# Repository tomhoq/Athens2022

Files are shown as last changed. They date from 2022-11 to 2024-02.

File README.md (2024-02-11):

# Athens2022-Madrid

Code for ESP32 client and server and Processing interface that display data.

With this project we came up with a solution for a long known problem present on our university: lack of studying spaces.

By using sensors on an Arduino board, connected wirelessly to a server, anyone is able to access, online, the occupancy of each studying room to 
make better decisions and to avoid having to walk the entire campus, up and down.

More on the functioning of the project can be found on the report.

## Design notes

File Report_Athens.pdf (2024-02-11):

### The doorman of the Future

A new approach to managing studying rooms

### UPM115 - Physical Computing based on Open Software and Hardware Platforms [EN]

Autores:

Ant´onio Vidais (IST - Lisboa) Tomaz Silva (IST - Lisboa) antonio.vidais@tecnico.ulisboa.pt tomaz.goncalves-silva@tecnico.ulisboa.pt

### Athens – Winter of 2022

IST | ULisboa

## 1 Introduction

The need for this system comes from the fact that every day, students trying to study on their college have to scour their entire college for a room where they can study. The Future Doorman solves this by sharing data from open rooms to everyone who needs it.
It is composed of 2 systems, a client that is attached to the door of each room and a server connected to a computer that can share the information either online or on a screen.

## 2 Choice of Hardware

### 2.1 Client

After some tries, we decided that the best platform available was the ESP32, because of the integrated Wifi module, without compromising on the number of GPIO pins and memory. However, choosing an ESP-WROOM-32 meant that 5v power wouldn’t be available. That meant that we couldn’t use ultrasound sensors. While searching for a 3.3v compatible distance sensor. We settled on LIDAR sensor because it provided the precision that the application requires and works on both 3.3v and 5v power.

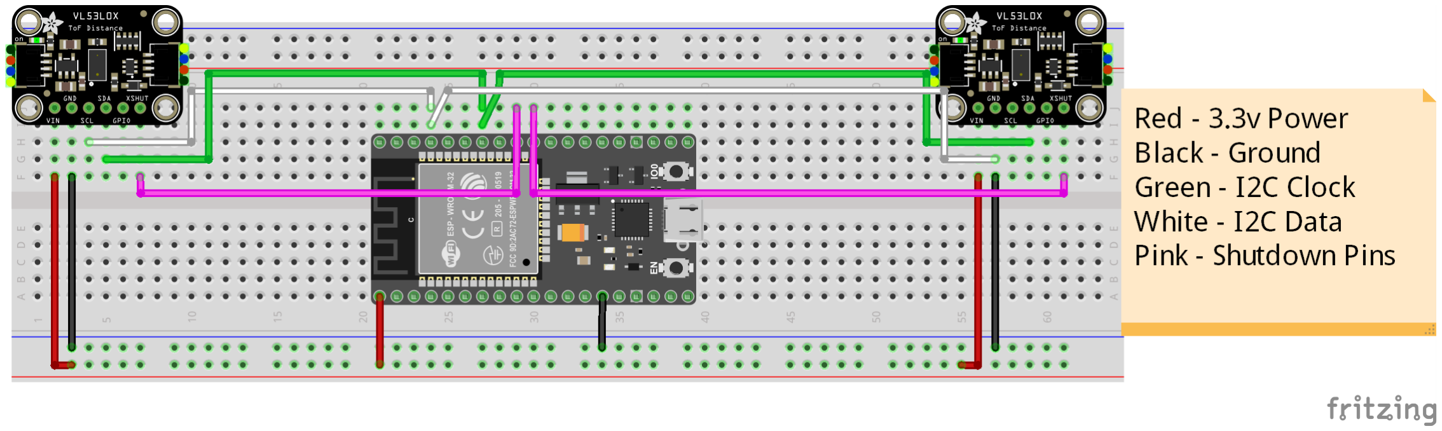
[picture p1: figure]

Figura 1: Client Schematic

### 2.2 Server

For the server we also wanted to use an ESP-WROOM-32 because of the compact size and, once again, the superior wifi module. The server doesn’t need any additional modules as it´s only function is to connect the server computer to the clients.

## 3 Hardware Limitations

As we tested the hardware, we realized that there was a limitation in the refresh rate of the LIDAR Sensors, as they would sometimes miss count if people are fast enough. This situation only happened rarely so it isn’t too much of a problem.
One Limitation that we couldn’t solve is that LIDAR sensors are dependent on colors, so we predict some unexpected behaviour if the background isn’t mono color.
We also noticed that the server and client would often have different refresh rates and getting them to match would be hard, so we had to separate the sensor reading from the data
Unidade Curricular | 1 | Curso

sending. We settled on using an HTTP server between the 2 modules, where the server requests data from the client and the client answers by sending both room and occupation data. This way both modules are independent and can work at different refresh rates.

## 4 Displaying data

To get the data from clients, the server sends multiple HTTP requests and then analyses the responses to get the data for each room. Responses give the server information on both room and occupation.
The data is displayed in a window as follows.
On the left side, the classrooms’ name surrounded by a color representing it’s percentage of occupation.
- Green: 0 to 30 percent of room is free;
- Yellow: 30 to 75 percent of the room is occupied;
- Red: More than 75 percent of the room is occupied;

(Note that it is possible to have more than 100 percent occupation and in this case it will also display red);

On the right of the classrooms’ name you can see how many people are inside the room and it’s maximum capacity.
On the right side of the window, 2 buttons that let the user sort the rooms in 2 ways that make it more convenient. One is alphabetically accordingly to the room’s name, and the other sorts based on the percentage of occupation of each room (from low to high).
In the case, where there are too many rooms and they don’t all fit in the windows’ resolution, a sliding animation begins, showing all the hidden rooms. Once it reaches the end, resets to the first room.
Unidade Curricular | 2 | Curso

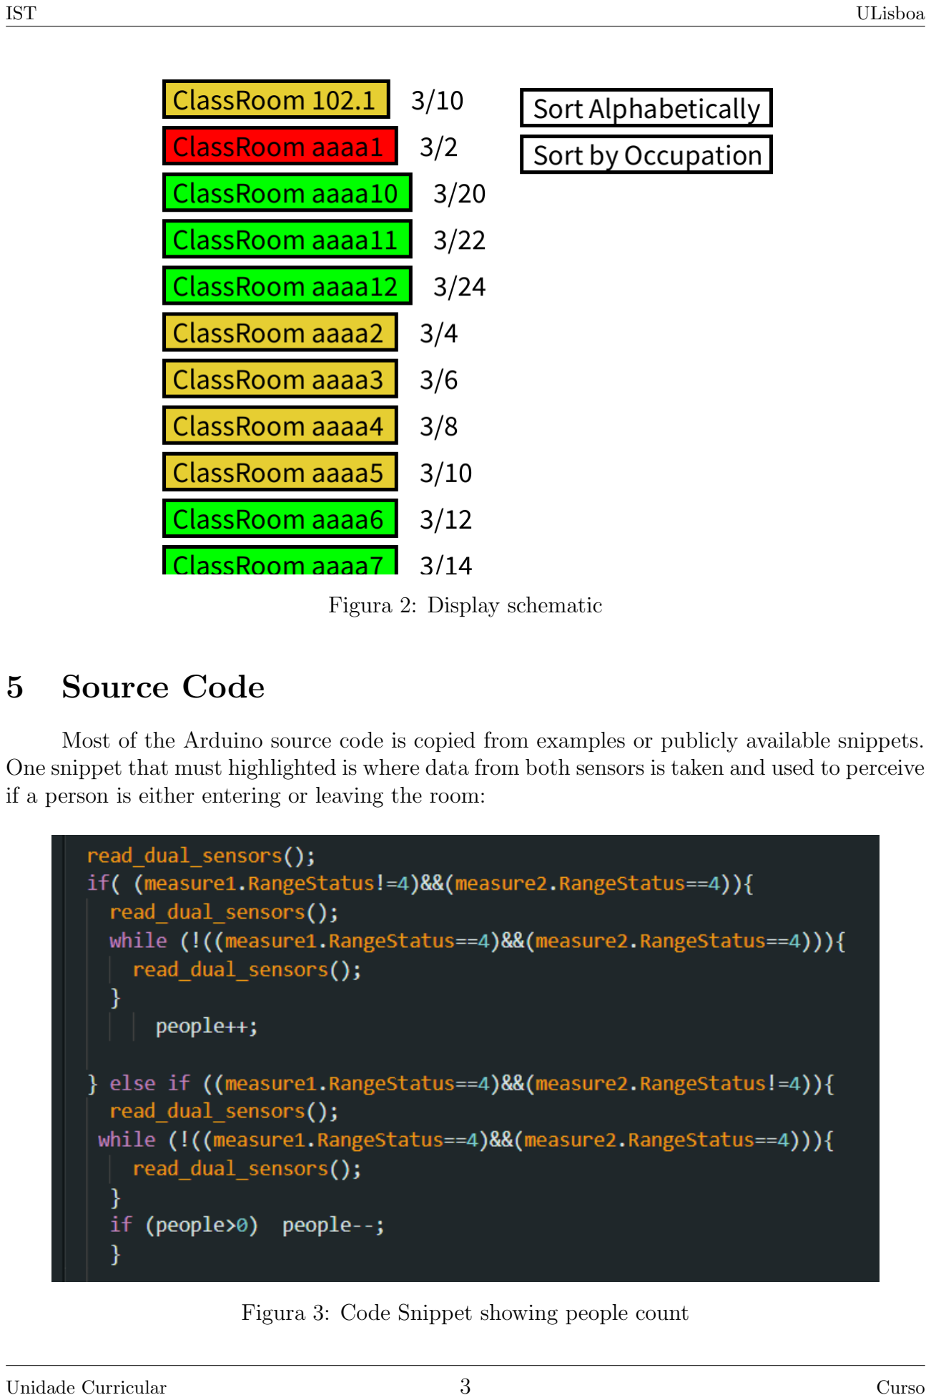
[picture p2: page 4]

Figura 2: Display schematic

## 5 Source Code

Most of the Arduino source code is copied from examples or publicly available snippets. One snippet that must highlighted is where data from both sensors is taken and used to perceive if a person is either entering or leaving the room:

Figura 3: Code Snippet showing people count

Unidade Curricular | 3 | Curso

The full source code can be found on GitHub (https://github.com/tomhoq/Athens2022.git)

## 6 Self-evaluation

### 6.1 What went wrong

There were some things that we intended to do extra but, unfortunately, due to issues with both breadboards and Arduino’s lost a lot of valuable time.

### 6.2 What went well

We were able to divide the work very efficiently with Ant´onio being responsible for designing and assembling the hardware (both client and server and the interaction between them) and Tomaz making sure the data gets treated, and then displaying it in an efficient and visually attractive User Interface.
By making the correct hardware choices, we were able to have a system that runs fully on 3.3v power, which reduces power consumption substantially.

### 6.3 The next steps

One important aspect this system lacks is the ability to calibrate the sensors. By having an initial measure of the background the system wouldn’t be as dependent on the LIDAR sensors accurate measuring.
This system has potential to grow if we wanted to. We can scale to it almost indefinitely because there isn’t a necessity for high refresh rates. One server can have many clients without problems which makes integration on big universities simpler than other systems.
The object of this system is to help students, so our initial idea was to have occupation data shown on an app (or a website), where students could quick and easily find a room to study in.

## 7 Conclusion

During this project we were challenged many times, with problems that an engineer designing a similar system only gets if he test real hardware. This is an important lesson in a world where everything is virtual. Our initial virtual designs appeared to work well but, as we found out, that wasn’t the case when it came to the real deal.

Unidade Curricular | 4 | Curso

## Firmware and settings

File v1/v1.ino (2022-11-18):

#include "Adafruit_VL53L0X.h"
#include "WiFi.h"
#include "ESPAsyncWebServer.h"

#include <Wire.h>

// address we will assign if dual sensor is present
#define LOX1_ADDRESS 0x30
#define LOX2_ADDRESS 0x31

// set the pins to shutdown
#define SHT_LOX1 19
#define SHT_LOX2 18

// objects for the vl53l0x
Adafruit_VL53L0X lox1 = Adafruit_VL53L0X();
Adafruit_VL53L0X lox2 = Adafruit_VL53L0X();

// this holds the measurement
VL53L0X_RangingMeasurementData_t measure1;
VL53L0X_RangingMeasurementData_t measure2;

int people=0;
String room="102.1";

// Set your access point network credentials
const char* ssid = "ESP32-Access-Point";
const char* password = "123456789";

/*
    Reset all sensors by setting all of their XSHUT pins low for delay(10), then set all XSHUT high to bring out of reset
    Keep sensor #1 awake by keeping XSHUT pin high
    Put all other sensors into shutdown by pulling XSHUT pins low
    Initialize sensor #1 with lox.begin(new_i2c_address) Pick any number but 0x29 and it must be under 0x7F. Going with 0x30 to 0x3F is probably OK.
    Keep sensor #1 awake, and now bring sensor #2 out of reset by setting its XSHUT pin high.
    Initialize sensor #2 with lox.begin(new_i2c_address) Pick any number but 0x29 and whatever you set the first sensor to
 */
void setID() {
  // all reset
  digitalWrite(SHT_LOX1, LOW);    
  digitalWrite(SHT_LOX2, LOW);
  delay(10);
  // all unreset
  digitalWrite(SHT_LOX1, HIGH);
  digitalWrite(SHT_LOX2, HIGH);
  delay(10);

  // activating LOX1 and resetting LOX2
  digitalWrite(SHT_LOX1, HIGH);
  digitalWrite(SHT_LOX2, LOW);

  // initing LOX1
  if(!lox1.begin(LOX1_ADDRESS)) {
    Serial.println(F("Failed to boot first VL53L0X"));
    while(1);
  }
  delay(10);

  // activating LOX2
  digitalWrite(SHT_LOX2, HIGH);
  delay(10);

  //initing LOX2
  if(!lox2.begin(LOX2_ADDRESS)) {
    Serial.println(F("Failed to boot second VL53L0X"));
    while(1);
  }
}

void read_dual_sensors() {
  
  lox1.rangingTest(&measure1, false); // pass in 'true' to get debug data printout!
  lox2.rangingTest(&measure2, false); // pass in 'true' to get debug data printout!

  // print sensor one reading
  Serial.print(F("1: "));
  if(measure1.RangeStatus != 4) {     // if not out of range
    Serial.print(measure1.RangeMilliMeter);
  } else {
    Serial.print(F("Out of range"));
  }
  
  Serial.print(F(" "));

  // print sensor two reading
  Serial.print(F("2: "));
  if(measure2.RangeStatus != 4) {
    Serial.print(measure2.RangeMilliMeter);
  } else {
    Serial.print(F("Out of range"));
  }
  
  Serial.println();
}
/*
void calibrate(){

  int sum1=0,n1=0,sum2=0,n2=0;

  while(digitalRead(cal_b)==HIGH){
    read_dual_sensors();
    sum1+=measure1.RangeMilliMeter;
    ave1=sum1/n1;
    n1++;
    sum2+=measure2.RangeMilliMeter;
    ave2=sum2/n2;
    n2++;
     Serial.println("Calibrating...");
  }
 
}
*/
String readP() {
  return String(room + "," +people);
}

void server_setup(){

/*
  Rui Santos
  Complete project details at https://RandomNerdTutorials.com/esp32-client-server-wi-fi/
  
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
  The above copyright notice and this permission notice shall be included in all
  copies or substantial portions of the Software.
*/
// Create AsyncWebServer object on port 80
  AsyncWebServer server(80);

  // Serial port for debugging purposes
  Serial.println();
  
  // Setting the ESP as an access point
  Serial.print("Setting AP (Access Point)…");
  // Remove the password parameter, if you want the AP (Access Point) to be open
  WiFi.softAP(ssid, password);

  IPAddress IP = WiFi.softAPIP();
  Serial.print("AP IP address: ");
  Serial.println(IP);

  server.on("/people", HTTP_GET, [](AsyncWebServerRequest *request){
    request->send_P(200, "text/plain", readP().c_str());
  });

  // Start server
  server.begin();
}



void setup() {
  Serial.begin(115200);

  // wait until serial port opens for native USB devices
  while (! Serial) { delay(1); }

  pinMode(SHT_LOX1, OUTPUT);
  pinMode(SHT_LOX2, OUTPUT);

  Serial.println(F("Shutdown pins inited..."));

  digitalWrite(SHT_LOX1, LOW);
  digitalWrite(SHT_LOX2, LOW);

  Serial.println(F("Both in reset mode...(pins are low)"));
  
  
  Serial.println(F("Starting..."));
  setID();

  server_setup();
 
}

void loop() {
  
  read_dual_sensors();
  if( (measure1.RangeStatus!=4)&&(measure2.RangeStatus==4)){
    read_dual_sensors();
    while (!((measure1.RangeStatus==4)&&(measure2.RangeStatus==4))){
      read_dual_sensors();
    }
        people++;
    
  } else if ((measure1.RangeStatus==4)&&(measure2.RangeStatus!=4)){
    read_dual_sensors();
   while (!((measure1.RangeStatus==4)&&(measure2.RangeStatus==4))){
      read_dual_sensors();
    }  
    if (people>0)  people--;
    }
  
  Serial.print(people);

  delay(100);
}

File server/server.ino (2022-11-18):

/*
  Rui Santos
  Complete project details at https://RandomNerdTutorials.com/esp32-client-server-wi-fi/
  
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
  The above copyright notice and this permission notice shall be included in all
  copies or substantial portions of the Software.
*/

#include <WiFi.h>
#include <HTTPClient.h>

const char* ssid = "ESP32-Access-Point";
const char* password = "123456789";

//Your IP address or domain name with URL path
const char* serverName = "http://192.168.4.1/people";

#include <Wire.h>


String people;

unsigned long previousMillis = 0;
const long interval = 5000; 

void setup() {
  Serial.begin(115200);
  
  WiFi.begin(ssid, password);
  Serial.println("Connecting");
  while(WiFi.status() != WL_CONNECTED) { 
    delay(500);
    Serial.print(".");
  }
  Serial.println("");
  Serial.print("Connected to WiFi network with IP Address: ");
  Serial.println(WiFi.localIP());
}

void loop() {
  unsigned long currentMillis = millis();
  
  if(currentMillis - previousMillis >= interval) {
     // Check WiFi connection status
    if(WiFi.status()== WL_CONNECTED ){ 
      
      people = httpGETRequest(serverName);

      Serial.println(people);
      
      // save the last HTTP GET Request
      previousMillis = currentMillis;
    }
    else {
      Serial.println("WiFi Disconnected");
    }
  }
}

String httpGETRequest(const char* serverName) {
  WiFiClient client;
  HTTPClient http;
    
  // Your Domain name with URL path or IP address with path
  http.begin(client, serverName);
  
  // Send HTTP POST request
  int httpResponseCode = http.GET();
  
  String payload = "--"; 
  
  //if (httpResponseCode>0) {
    Serial.print("HTTP Response code: ");
    Serial.println(httpResponseCode);
    payload = http.getString();
  //}
 // else {
   // Serial.print("Error code: ");
   // Serial.println(httpResponseCode);
  //}
  // Free resources
  http.end();

  return payload;
}

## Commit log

2022-11-16 new file: arduinoSensor/arduinoSensor.ino
2022-11-16 Client Breadboard design is mostly complete
    new file: client_v1.fzz
    [client_v1.fzz]
2022-11-16 modified: client_v1.fzz
    [client_v1.fzz]
2022-11-18 renamed: Processing/Room.pde -> Processing/RoomClass.pde modified: Processing/manager.pde deleted: arduinoSensor/arduinoReceiver.ino/arduinoReceiver.ino.ino deleted: arduinoSensor/arduinoSensor.ino
2022-11-18 new file: client_final.png modified: client_v1.fzz new file: i2c/i2c.ino new file: v1/v1.ino
    [client_v1.fzz]
2022-11-18 new file: client/v1.ino new file: server/server.ino deleted: arduinoSensor/arduinoSensor.ino deleted: client_final.png deleted: v1/v1.ino
